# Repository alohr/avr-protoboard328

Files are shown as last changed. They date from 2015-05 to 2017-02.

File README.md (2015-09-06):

avr-protoboard328
=================

A prototyping board for the AVR atmega328p. 

## Images

<p align="center">
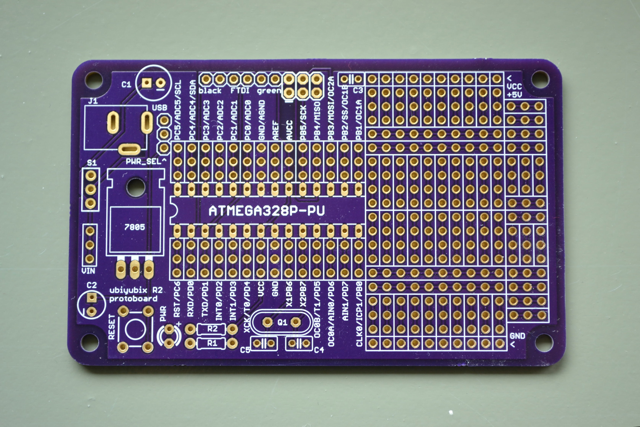
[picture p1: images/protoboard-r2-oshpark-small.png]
r2 from oshpark
  
</p>

<p align="center">
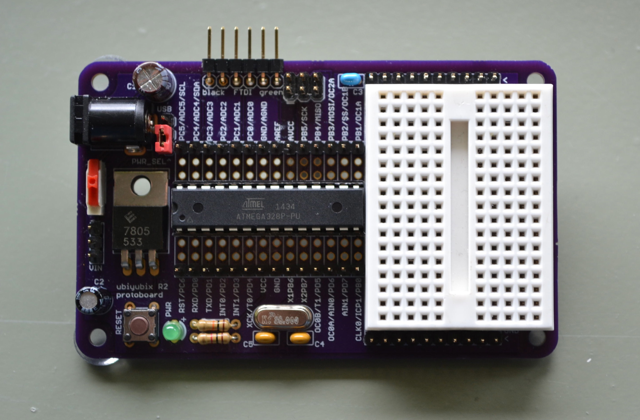
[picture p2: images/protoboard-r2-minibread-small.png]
r2 from oshpark w/ mini breadboard
  
</p>

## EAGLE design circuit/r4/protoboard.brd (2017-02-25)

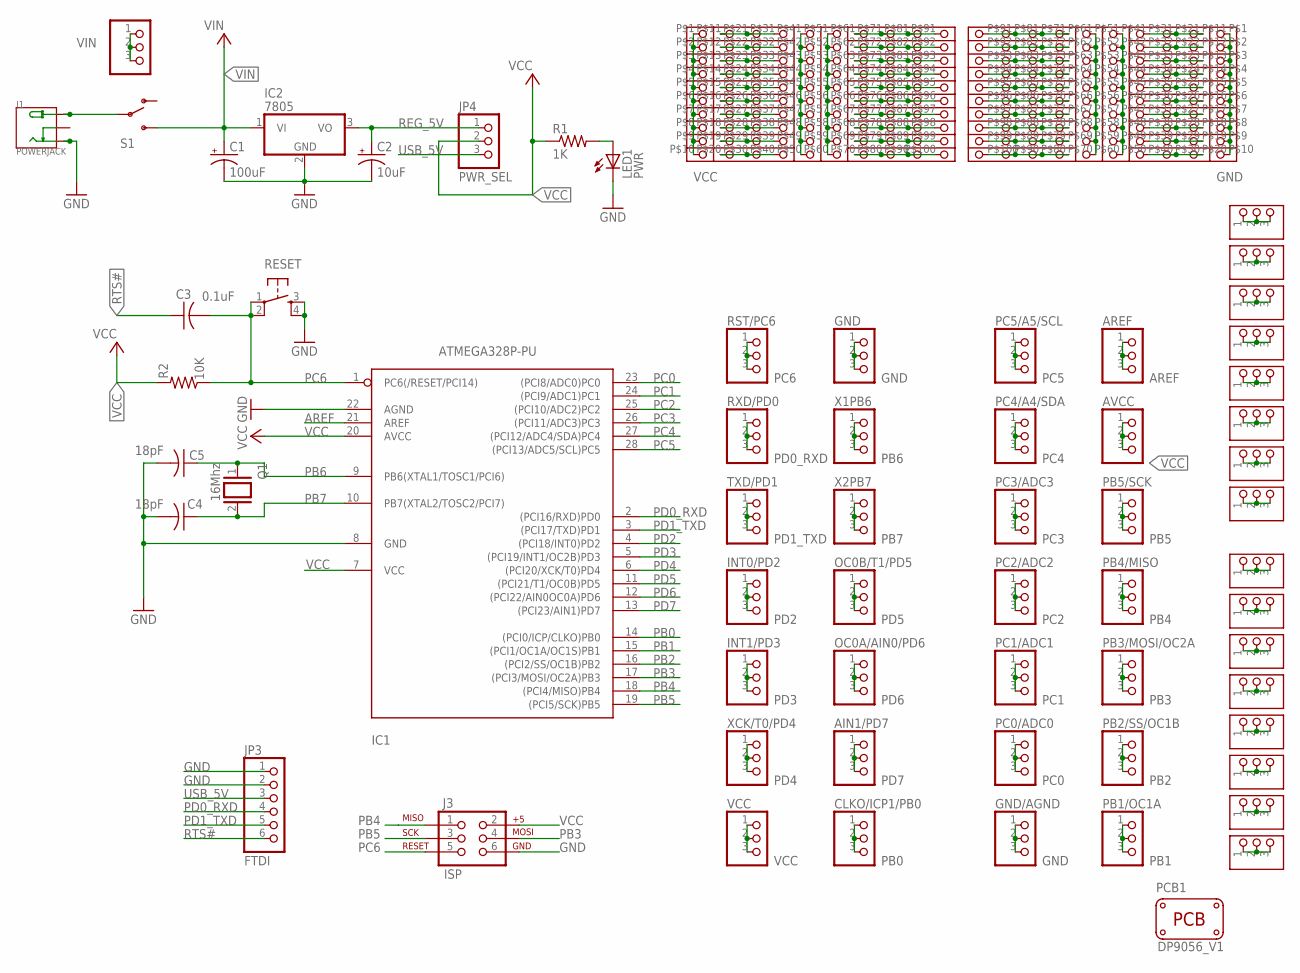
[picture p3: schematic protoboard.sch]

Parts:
AIN1/PD7: PINHD-1X3; 1X03
AREF: PINHD-1X3; 1X03
AVCC: PINHD-1X3; 1X03
C1: 100uF; CPOL-RADIAL-100UF-25V
C2: 10uF; CPOL-RADIAL-10UF-25V
C3: 0.1uF; C025-025X050
C4, C5: 18pF; C025-025X050
CLKO/ICP1/PB0: PINHD-1X3; 1X03
GND: PINHD-1X3; 1X03
GND/AGND: PINHD-1X3; 1X03
IC1: ATMEGA328P-PU; DIL28-3
IC2: 7805; TO220H
INT0/PD2, INT1/PD3: PINHD-1X3; 1X03
J1: POWERJACK; PW-3P-2.1
J3: ISP; 2X3
JP3: FTDI; 1X06
JP4: PWR_SEL; 1X03
LED1: PWR; LED3MM
OC0A/AIN0/PD6, OC0B/T1/PD5: PINHD-1X3; 1X03
PB1/OC1A, PB2/SS/OC1B, PB3/MOSI/OC2A, PB4/MISO, PB5/SCK: PINHD-1X3; 1X03
PC0/ADC0, PC1/ADC1, PC2/ADC2, PC3/ADC3, PC4/A4/SDA, PC5/A5/SCL: PINHD-1X3; 1X03
PCB1: PCB_DP_RECTANGLE-56X90; DP9056_V1
Q1: 16Mhz; QS
R1: 1K; 0207/7
R2: 10K; 0207/7
RESET: TAC_SWITCHPTH; TACTILE-PTH
RST/PC6: PINHD-1X3; 1X03
RXD/PD0: PINHD-1X3; 1X03
S1: SWITCH-SPDTPTH; SWITCH-SPDT
TXD/PD1: PINHD-1X3; 1X03
U$1, U$3: PROTOFIELD-10X10
U$4, U$5, U$6, U$7, U$8, U$9, U$10, U$11, U$12, U$13, U$14, U$15, U$16, U$17, U$18, U$19: PROTOFIELD-3
VCC: PINHD-1X3; 1X03
VIN: +9V; 1X03
X1PB6, X2PB7: PINHD-1X3; 1X03
XCK/T0/PD4: PINHD-1X3; 1X03

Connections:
AREF: AREF.1, AREF.2, AREF.3, IC1.21 (AREF)
GND: C1.2 (-), C2.2 (-), C4.2, C5.2, GND.1, GND.2, GND.3, GND/AGND.1, GND/AGND.2, GND/AGND.3, IC1.8 (GND), IC1.22 (AGND), IC2.2 (GND), J1.-1 (-), J3.6, JP3.1, JP3.2, LED1.K (C), RESET.3, RESET.4, U$3.P$1 (1), U$3.P$2 (5), U$3.P$3, U$3.P$4, U$3.P$5, U$3.P$6, U$3.P$7, U$3.P$8, U$3.P$9, U$3.P$10
unnamed: J1.+, S1.2
unnamed: LED1.A, R1.2
unnamed: U$4.1, U$4.2, U$4.3
unnamed: U$5.1, U$5.2, U$5.3
unnamed: U$6.1, U$6.2, U$6.3
unnamed: U$7.1, U$7.2, U$7.3
unnamed: U$8.1, U$8.2, U$8.3
unnamed: U$9.1, U$9.2, U$9.3
unnamed: U$10.1, U$10.2, U$10.3
unnamed: U$11.1, U$11.2, U$11.3
unnamed: U$12.1, U$12.2, U$12.3
unnamed: U$13.1, U$13.2, U$13.3
unnamed: U$14.1, U$14.2, U$14.3
unnamed: U$15.1, U$15.2, U$15.3
unnamed: U$16.1, U$16.2, U$16.3
unnamed: U$17.1, U$17.2, U$17.3
unnamed: U$18.1, U$18.2, U$18.3
unnamed: U$19.1, U$19.2, U$19.3
unnamed: U$1.P$41, U$1.P$42, U$1.P$43, U$1.P$44, U$1.P$45, U$1.P$46, U$1.P$47, U$1.P$48, U$1.P$49, U$1.P$50
unnamed: U$1.P$51, U$1.P$52, U$1.P$53, U$1.P$54, U$1.P$55, U$1.P$56, U$1.P$57, U$1.P$58, U$1.P$59, U$1.P$60
unnamed: U$1.P$61, U$1.P$71, U$1.P$81, U$1.P$91
unnamed: U$1.P$62, U$1.P$72, U$1.P$82, U$1.P$92
unnamed: U$1.P$63, U$1.P$73, U$1.P$83, U$1.P$93
unnamed: U$1.P$64, U$1.P$74, U$1.P$84, U$1.P$94
unnamed: U$1.P$65, U$1.P$75, U$1.P$85, U$1.P$95
unnamed: U$1.P$66, U$1.P$76, U$1.P$86, U$1.P$96
unnamed: U$1.P$67, U$1.P$77, U$1.P$87, U$1.P$97
unnamed: U$1.P$68, U$1.P$78, U$1.P$88, U$1.P$98
unnamed: U$1.P$69, U$1.P$79, U$1.P$89, U$1.P$99
unnamed: U$1.P$70, U$1.P$80, U$1.P$90, U$1.P$100
unnamed: U$1.P$11 (2), U$1.P$21 (3), U$1.P$31 (4)
unnamed: U$1.P$12 (6), U$1.P$22 (7), U$1.P$32 (8)
unnamed: U$1.P$13, U$1.P$23, U$1.P$33
unnamed: U$1.P$14, U$1.P$24, U$1.P$34
unnamed: U$1.P$15, U$1.P$25, U$1.P$35
unnamed: U$1.P$16, U$1.P$26, U$1.P$36
unnamed: U$1.P$17, U$1.P$27, U$1.P$37
unnamed: U$1.P$18, U$1.P$28, U$1.P$38
unnamed: U$1.P$19, U$1.P$29, U$1.P$39
unnamed: U$1.P$20, U$1.P$30, U$1.P$40
unnamed: U$3.P$61, U$3.P$71, U$3.P$81, U$3.P$91
unnamed: U$3.P$62, U$3.P$72, U$3.P$82, U$3.P$92
unnamed: U$3.P$63, U$3.P$73, U$3.P$83, U$3.P$93
unnamed: U$3.P$64, U$3.P$74, U$3.P$84, U$3.P$94
unnamed: U$3.P$65, U$3.P$75, U$3.P$85, U$3.P$95
unnamed: U$3.P$66, U$3.P$76, U$3.P$86, U$3.P$96
unnamed: U$3.P$67, U$3.P$77, U$3.P$87, U$3.P$97
unnamed: U$3.P$68, U$3.P$78, U$3.P$88, U$3.P$98
unnamed: U$3.P$69, U$3.P$79, U$3.P$89, U$3.P$99
unnamed: U$3.P$70, U$3.P$80, U$3.P$90, U$3.P$100
unnamed: U$3.P$51, U$3.P$52, U$3.P$53, U$3.P$54, U$3.P$55, U$3.P$56, U$3.P$57, U$3.P$58, U$3.P$59, U$3.P$60
unnamed: U$3.P$41, U$3.P$42, U$3.P$43, U$3.P$44, U$3.P$45, U$3.P$46, U$3.P$47, U$3.P$48, U$3.P$49, U$3.P$50
unnamed: U$3.P$11 (2), U$3.P$21 (3), U$3.P$31 (4)
unnamed: U$3.P$12 (6), U$3.P$22 (7), U$3.P$32 (8)
unnamed: U$3.P$13, U$3.P$23, U$3.P$33
unnamed: U$3.P$14, U$3.P$24, U$3.P$34
unnamed: U$3.P$15, U$3.P$25, U$3.P$35
unnamed: U$3.P$16, U$3.P$26, U$3.P$36
unnamed: U$3.P$17, U$3.P$27, U$3.P$37
unnamed: U$3.P$18, U$3.P$28, U$3.P$38
unnamed: U$3.P$19, U$3.P$29, U$3.P$39
unnamed: U$3.P$20, U$3.P$30, U$3.P$40
PB0: CLKO/ICP1/PB0.1, CLKO/ICP1/PB0.2, CLKO/ICP1/PB0.3, IC1.14 ((PCI0/ICP/CLKO)PB0)
PB1: IC1.15 ((PCI1/OC1A/OC1S)PB1), PB1/OC1A.1, PB1/OC1A.2, PB1/OC1A.3
PB2: IC1.16 ((PCI2/SS/OC1B)PB2), PB2/SS/OC1B.1, PB2/SS/OC1B.2, PB2/SS/OC1B.3
PB3: IC1.17 ((PCI3/MOSI/OC2A)PB3), J3.4, PB3/MOSI/OC2A.1, PB3/MOSI/OC2A.2, PB3/MOSI/OC2A.3
PB4: IC1.18 ((PCI4/MISO)PB4), J3.1, PB4/MISO.1, PB4/MISO.2, PB4/MISO.3
PB5: IC1.19 ((PCI5/SCK)PB5), J3.3, PB5/SCK.1, PB5/SCK.2, PB5/SCK.3
PB6: C5.1, IC1.9 (PB6(XTAL1/TOSC1/PCI6)), Q1.1, X1PB6.1, X1PB6.2, X1PB6.3
PB7: C4.1, IC1.10 (PB7(XTAL2/TOSC2/PCI7)), Q1.2, X2PB7.1, X2PB7.2, X2PB7.3
PC0: IC1.23 ((PCI8/ADC0)PC0), PC0/ADC0.1, PC0/ADC0.2, PC0/ADC0.3
PC1: IC1.24 ((PCI9/ADC1)PC1), PC1/ADC1.1, PC1/ADC1.2, PC1/ADC1.3
PC2: IC1.25 ((PCI10/ADC2)PC2), PC2/ADC2.1, PC2/ADC2.2, PC2/ADC2.3
PC3: IC1.26 ((PCI11/ADC3)PC3), PC3/ADC3.1, PC3/ADC3.2, PC3/ADC3.3
PC4: IC1.27 ((PCI12/ADC4/SDA)PC4), PC4/A4/SDA.1, PC4/A4/SDA.2, PC4/A4/SDA.3
PC5: IC1.28 ((PCI13/ADC5/SCL)PC5), PC5/A5/SCL.1, PC5/A5/SCL.2, PC5/A5/SCL.3
PC6: C3.2, IC1.1 (PC6(/RESET/PCI14)), J3.5, R2.1, RESET.1, RESET.2, RST/PC6.1, RST/PC6.2, RST/PC6.3
PD0_RXD: IC1.2 ((PCI16/RXD)PD0), JP3.4, RXD/PD0.1, RXD/PD0.2, RXD/PD0.3
PD1_TXD: IC1.3 ((PCI17/TXD)PD1), JP3.5, TXD/PD1.1, TXD/PD1.2, TXD/PD1.3
PD2: IC1.4 ((PCI18/INT0)PD2), INT0/PD2.1, INT0/PD2.2, INT0/PD2.3
PD3: IC1.5 ((PCI19/INT1/OC2B)PD3), INT1/PD3.1, INT1/PD3.2, INT1/PD3.3
PD4: IC1.6 ((PCI20/XCK/T0)PD4), XCK/T0/PD4.1, XCK/T0/PD4.2, XCK/T0/PD4.3
PD5: IC1.11 ((PCI21/T1/OC0B)PD5), OC0B/T1/PD5.1, OC0B/T1/PD5.2, OC0B/T1/PD5.3
PD6: IC1.12 ((PCI22/AIN0OC0A)PD6), OC0A/AIN0/PD6.1, OC0A/AIN0/PD6.2, OC0A/AIN0/PD6.3
PD7: AIN1/PD7.1, AIN1/PD7.2, AIN1/PD7.3, IC1.13 ((PCI23/AIN1)PD7)
REG_5V: C2.1 (+), IC2.3 (VO), JP4.1
RTS#: C3.1, JP3.6
USB_5V: JP3.3, JP4.3
VCC: AVCC.1, AVCC.2, AVCC.3, IC1.7 (VCC), IC1.20 (AVCC), J3.2, JP4.2, R1.1, R2.2, U$1.P$1 (1), U$1.P$2 (5), U$1.P$3, U$1.P$4, U$1.P$5, U$1.P$6, U$1.P$7, U$1.P$8, U$1.P$9, U$1.P$10, VCC.1, VCC.2, VCC.3
VIN: C1.1 (+), IC2.1 (VI), S1.3 (S), VIN.1, VIN.2, VIN.3

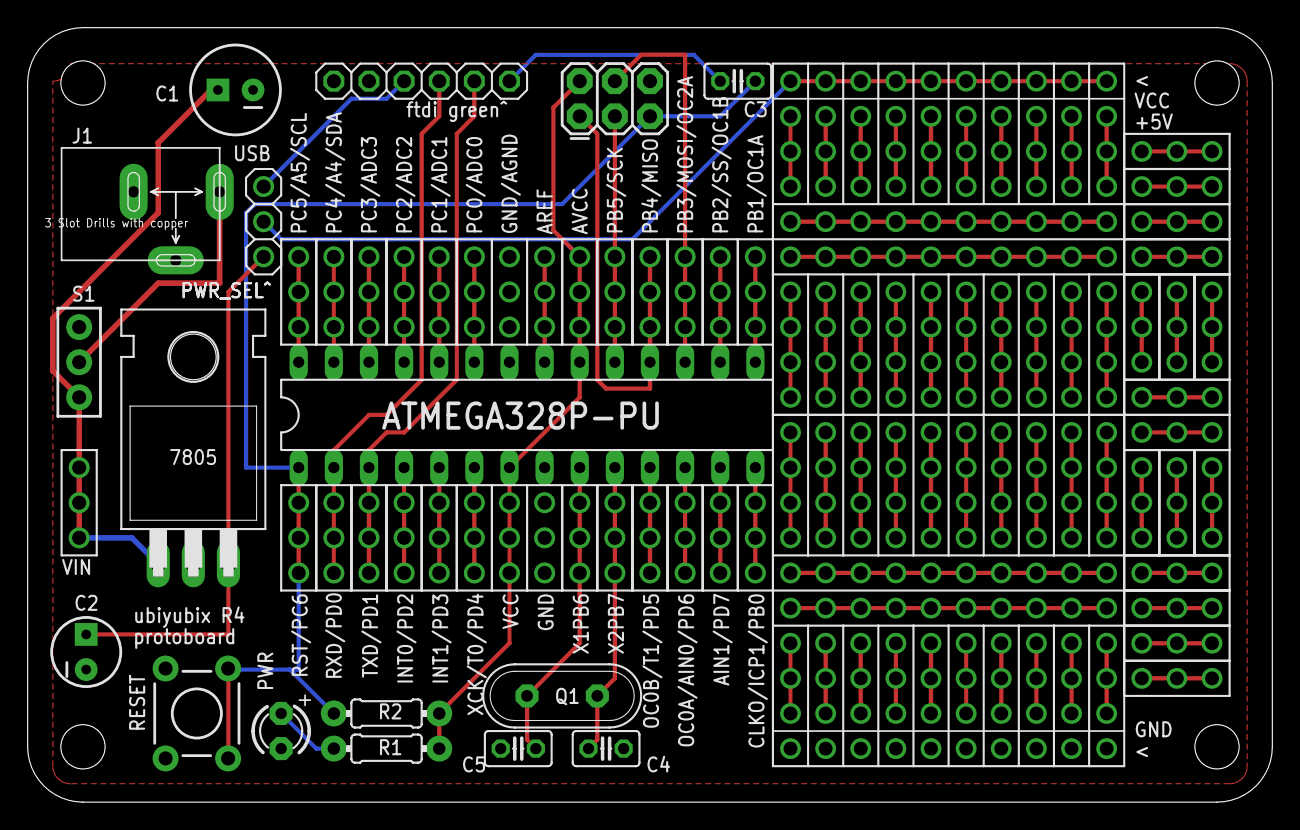
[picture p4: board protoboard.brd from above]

Board: 2 copper layers, 90.0 x 56.0 mm, 65 parts (0 on the bottom side), 92 nets.

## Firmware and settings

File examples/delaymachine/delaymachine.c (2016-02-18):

#include <avr/io.h>
#include <avr/interrupt.h>
#include <util/delay.h>

#include "timer0.h"

//                           +-\/-+
//               reset PC6  1|    |28  PC5 display cathode 3
// display anode seg A PD0  2|    |27  PC4 display cathode 2
// display anode seg B PD1  3|    |26  PC3 display cathode 1
// display anode seg C PD2  4|    |25  PC2 display cathode 0
// display anode seg D PD3  5|    |24  PC1
// display anode seg E PD4  6|    |23  PC0 ADC0 potentiometer
//                     VCC  7|    |22  GND
//                     GND  8|    |21  AREF
//               XTAL1 PB6  9|    |20  AVCC
//               XTAL2 PB7 10|    |19  PB5
// display anode seg F PD5 11|    |18  PB4
// display anode seg G PD6 12|    |17  PB3
//       push button 2 PD7 13|    |16  PB2 led cathode
//       push button 1 PB0 14|    |15  PB1 OC1A pwm output
//                           +----+

#if F_CPU == 1000000
  #define TIMER2_PRESCALE 8
#elif F_CPU == 8000000 || F_CPU == 16000000
  #define TIMER2_PRESCALE 64
#else
  #error F_CPU not recognized
#endif

enum {
    TIMER2_RESET_TO_400_MICROS = 256 - (F_CPU / TIMER2_PRESCALE / 2500),

    PIN_LED = PB2,
    PIN_BUTTON1 = PB0,
    PIN_BUTTON2 = PD7,

    PIN_CATHODE_DIGIT_0 = PC2,
    PIN_CATHODE_DIGIT_1 = PC3,
    PIN_CATHODE_DIGIT_2 = PC4,
    PIN_CATHODE_DIGIT_3 = PC5,
    PIN_CATHODES_MASK = (_BV(PIN_CATHODE_DIGIT_0) | _BV(PIN_CATHODE_DIGIT_1) |
                         _BV(PIN_CATHODE_DIGIT_2) | _BV(PIN_CATHODE_DIGIT_3)),

    PIN_ANODE_SEG_A = PD0,
    PIN_ANODE_SEG_B = PD1,
    PIN_ANODE_SEG_C = PD2,
    PIN_ANODE_SEG_D = PD3,
    PIN_ANODE_SEG_E = PD4,
    PIN_ANODE_SEG_F = PD5,
    PIN_ANODE_SEG_G = PD6,
    PIN_ANODES_MASK = (_BV(PIN_ANODE_SEG_A) | _BV(PIN_ANODE_SEG_B) | _BV(PIN_ANODE_SEG_C) |
                       _BV(PIN_ANODE_SEG_D) | _BV(PIN_ANODE_SEG_E) | _BV(PIN_ANODE_SEG_F) |
                       _BV(PIN_ANODE_SEG_G))
};

static int segment[] = {
    0b00111111, // 0
    0b00000110, // 1
    0b01011011, // 2
    0b01001111, // 3
    0b01100110, // 4
    0b01101101, // 5
    0b01111101, // 6
    0b00000111, // 7
    0b01111111, // 8
    0b01101111, // 9
};

typedef struct {
    uint8_t digits[4];
    uint8_t digit;
    uint8_t segment;
    int value;
    int on;
} display_t;

typedef struct {
    int raw, prevraw;
    int v;
    long t;
} analogvalue_t;

static volatile display_t display;

static void display_update(volatile display_t *d)
{
    if (d->on) {
        // digit
        uint8_t port_c = PORTC;
        port_c |= PIN_CATHODES_MASK;

        switch (d->digit) {
        case 0:
            port_c &= ~_BV(PIN_CATHODE_DIGIT_0);
            break;
        case 1:
            if (d->digits[1] != 0)
                port_c &= ~_BV(PIN_CATHODE_DIGIT_1);
            break;
        case 2:
            if (d->digits[2] != 0)
                port_c &= ~_BV(PIN_CATHODE_DIGIT_2);
            break;
        case 3:
            if (d->digits[3] != 0)
                port_c &= ~_BV(PIN_CATHODE_DIGIT_3);
            break;
        }

        PORTC = port_c;

        // segment
        int value = d->digits[d->digit];
        uint8_t port_d = (PORTD & _BV(PD7));
        PORTD = (segment[value] & _BV(d->segment)) | port_d;

        if (++d->segment == 7) {
            d->segment = 0;
            if (++d->digit == 4)
                d->digit = 0;
        }
    }
}

static void display_on(volatile display_t *d, int on)
{
    cli();
    d->on = on;
    sei();
}

static void display_off(volatile display_t *d)
{
    display_on(d, 0);
}

void display_toggle(volatile display_t *d)
{
    cli();
    d->on = !d->on;
    if (!d->on)
        display_off(d);
    sei();
}

static void display_set(volatile display_t *d, int value)
{
    d->digits[0] = value % 10;
    d->digits[1] = (value / 10) % 10;
    d->digits[2] = (value / 100) % 10;
    d->digits[3] = (value / 1000) % 10;
    d->value = value;
}

ISR(TIMER2_OVF_vect)
{
    // timer interrupt overflows every 400 microseconds
    TCNT2 = TIMER2_RESET_TO_400_MICROS;
    display_update(&display);
}

void setup_timer2(void)
{
#if F_CPU == 8000000
    // prescale /32
    TCCR2A = 0;
    TCCR2B = _BV(CS21) | _BV(CS20);
#elif F_CPU == 16000000
    // prescale /64
    TCCR2A = 0;
    TCCR2B = _BV(CS22);
#else
#error F_CPU not recognized
#endif

    // overflow interrupt enable
    TIMSK2 |= _BV(TOIE2);
    TCNT2 = TIMER2_RESET_TO_400_MICROS;

    sei();
}

void setup(void)
{
    // turn rx/tx on PD0 and PD1 off
    UCSR0B = 0;

    // display anodes PD0 .. PD6
    DDRD = PIN_ANODES_MASK;

    // display cathodes
    DDRC = PIN_CATHODES_MASK;
    PORTC |= PIN_CATHODES_MASK;

    // Set ADC prescaler /128, 16 Mhz / 128 = 125 KHz which is inside
    // the desired 50-200 KHz range
    ADCSRA = _BV(ADEN) | _BV(ADPS2) | _BV(ADPS1) | _BV(ADPS0);

    // LED pin
    DDRB |= _BV(PIN_LED);
    PORTB |= _BV(PIN_LED);
}

void analog_init(analogvalue_t *value)
{
    value->raw = 0;
    value->prevraw = 0;
    value->v = 0;
    value->t = millis();
}

int analog_read(int chan, analogvalue_t *value)
{
    uint8_t low, high;

    // AVCC with external capacitor at AREF pin, select channel
    ADMUX = (_BV(REFS0) | (chan & 0x0f));

    // start single conversion
    ADCSRA |= _BV(ADSC);

    // wait for conversion to complete
    loop_until_bit_is_clear(ADCSRA, ADSC);

    low  = ADCL;
    high = ADCH;

    value->raw = (high << 8) | low;
    value->t = millis();

    return value->raw;
}

int potentiometer_read(analogvalue_t *value)
{
    analogvalue_t newvalue;
    enum { CHANNEL = 0, N_READINGS = 3 };

    int raw = 0;
    for (int i = 0; i < N_READINGS; i++) {
        analog_read(CHANNEL, &newvalue);
        raw += newvalue.raw;
    }

    newvalue.raw = raw / N_READINGS;
    if (newvalue.raw > 1020)
        newvalue.raw = 1020;

    if ((newvalue.raw > value->prevraw && newvalue.raw - value->prevraw > 3) ||
        (newvalue.raw < value->prevraw && value->prevraw - newvalue.raw > 3)) {

        if (newvalue.t - value->t > 50) {
            value->prevraw = value->raw;
            value->raw = newvalue.raw;
            value->v = newvalue.raw / 4;
            value->t = newvalue.t;
        }
    }

    return value->v;
}

void settle_on_low(volatile uint8_t *port, uint8_t mask)
{
    long t = 0, t0 = 0;
    enum { SETTLE_ON_LOW_TIMEOUT_MS = 20 };

    loop_until_bit_is_clear(*port, mask);
    t0 = millis();

    // now wait for pin to stay low for at least x milliseconds
    while ((t = millis()) - t0 < SETTLE_ON_LOW_TIMEOUT_MS) {
	if (bit_is_set(*port, mask))
	    t0 = millis();
    }
}

/*
void setup_int0(void)
{
    // set INT0 to trigger on falling edge
    EICRA |= _BV(ISC01);
    EICRA &= ~_BV(ISC00);
}

void enable_int0()
{
    EIMSK |= _BV(INT0);
}

void disable_int0()
{
    EIMSK &= ~_BV(INT0);
}
*/

/* volatile long t0 = 0; */

/* ISR(INT0_vect) */
/* { */
/*     disable_int0(); */
/*     t0 = micros(); */
/* } */

int main(void)
{
    analogvalue_t delay;

    setup();
    setup_timer0();

    // setup_int0();

    // display_off(&display);
    setup_timer2();

    analog_init(&delay);
    potentiometer_read(&delay);

    display_set(&display, delay.v);
    display_on(&display, 1);

    /* if ((PIND & _BV(PIN_SW1)) == 0) */
    /*     pin = PIN_LED_RED; */

    for (;;) {
        if ((PIND & _BV(PIN_BUTTON2)) == 0) {
            PORTB &= _BV(PIN_LED);
        } else {
            PORTB |= _BV(PIN_LED);
        }



/*
        if ((PIND & _BV(PIN_SW1)) == 0) {
            long tmax = 1000L * delay.v;
            while (micros() - t0 < tmax)
                ;
            PORTD |= _BV(pin);
        } else {
            PORTD &= ~_BV(pin);
            enable_int0();
        }

        if ((PIND & _BV(PIN_SW2)) == 0) {
            settle_on_low(&PIND, PIN_SW2);
            loop_until_bit_is_set(PIND, PIN_SW2);
            display_toggle(&display);
        }
*/

        potentiometer_read(&delay);
        if (delay.v != display.value) {
            display_set(&display, delay.v);
        }
    }

    return 0;
}

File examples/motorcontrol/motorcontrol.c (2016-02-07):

#include <avr/io.h>
#include <avr/interrupt.h>
#include <util/delay.h>

//#define ONE_DIRECTION 
#define TWO_DIRECTIONS

#if !defined(ONE_DIRECTION) && !defined(TWO_DIRECTIONS)
#error Must define either ONE_DIRECTION or TWO_DIRECTIONS
#elif defined(ONE_DIRECTION) && defined(TWO_DIRECTIONS)
#error Must not define ONE_DIRECTION and TWO_DIRECTIONS
#endif

#define TIMER1_CLKFUDGE 3
#define TIMER1_GETVALUE(x) ((x) >> 1)

#define TIMER2_PRESCALE_DIVIDER 256
#define PWM_MIN 0x40
#define PWM_MAX 0xff

#define PULSEWIDTH_MARGIN 10
#define PULSEWIDTH_MIN 1000
#define PULSEWIDTH_MID 1500
#define PULSEWIDTH_MAX 2000

#define BACKWARD 0
#define FORWARD 1

// --------------------------
// TIMER1 - input capture
// --------------------------

volatile uint16_t pulsewidth = 0; // set by TIMER1_CAPT_vect interrupt routine

ISR(TIMER1_CAPT_vect)
{
    uint16_t icr1 = ICR1;
    TCNT1 = 0;

    if (bit_is_set(TCCR1B, ICES1)) {
        // was rising edge -> set to detect falling edge
        TCCR1B &= ~_BV(ICES1);
    } else {
        pulsewidth = icr1 + TIMER1_CLKFUDGE;
        // was falling -> now set to detect rising edge
        TCCR1B |= _BV(ICES1);
    }
}

void setup_timer1(void)
{
    TCCR1A = 0;

    TCCR1B |= _BV(ICES1); // trigger input capture on rising edge
    TCCR1B |= _BV(CS11);  // set prescaler /8

    TIMSK1 = _BV(ICIE1);  // input capture interrupt enable
}

// --------------------------
// TIMER2 - motor pwm control
// --------------------------

void setup_timer2(void)
{
    TCCR2A = 0;
    TCCR2B = 0;

#if F_CPU == 16000000
#if TIMER2_PRESCALE_DIVIDER == 1
    // no prescale 
    TCCR2B &= ~_BV(CS22);
    TCCR2B &= ~_BV(CS21);
    TCCR2B |= _BV(CS20);
#elif TIMER2_PRESCALE_DIVIDER == 8
    // prescale /8
    TCCR2B &= ~_BV(CS22);
    TCCR2B |= _BV(CS21);
    TCCR2B &= ~_BV(CS20);
#elif TIMER2_PRESCALE_DIVIDER == 32
    // prescale /32
    TCCR2B &= ~_BV(CS22);
    TCCR2B |= _BV(CS21);
    TCCR2B |= _BV(CS20);
#elif TIMER2_PRESCALE_DIVIDER == 64
    // prescale /64
    TCCR2B |= _BV(CS22);
    TCCR2B &= ~_BV(CS21);
    TCCR2B &= ~_BV(CS20);
#elif TIMER2_PRESCALE_DIVIDER == 256
    // prescale /256
    TCCR2B |= _BV(CS22);
    TCCR2B |= _BV(CS21);
    TCCR2B &= ~_BV(CS20);
#elif TIMER2_PRESCALE_DIVIDER == 1024
    // prescale /1024
    TCCR2B |= _BV(CS22);
    TCCR2B |= _BV(CS21);
    TCCR2B |= _BV(CS20);
#else
#error TIMER2_PRESCALE_DIVIDER not set correctly
#endif
#else
#error F_CPU not recognized
#endif

    // fast pwm mode 3
    TCCR2A |= _BV(WGM21) | _BV(WGM20);
    TCCR2B &= ~_BV(WGM22);
}

void timer2_set_oc2a(uint8_t ocr2a)
{
    if (ocr2a) {
        // clear OC2A on compare match (non-inverting mode)
        TCCR2A |= _BV(COM2A1);
        TCCR2A &= ~_BV(COM2A0);
        OCR2A = ocr2a;
    } else {
        // OC2A disconnected
        TCCR2A &= ~(_BV(COM2A1) | _BV(COM2A0));
    }
}

void setup(void)
{
    setup_timer1();
    setup_timer2();

    DDRB &= ~_BV(PB0); // ICP1 input pin = PB0
    
    // LD293 control pins
    DDRB |= _BV(PB1) | _BV(PB2) | _BV(PB3);
}

long map(int x, long in_min, long in_max, long out_min, long out_max)
{
    return (x - in_min) * (out_max - out_min) / (in_max - in_min) + out_min;
}

void set_motor_pins(int direction, uint8_t pwm)
{
    if (pwm != 0 && direction == BACKWARD) {
        PORTB &= ~_BV(PB2);
        PORTB |= _BV(PB1);
    } else if (pwm != 0 && direction == FORWARD) {
        PORTB &= ~_BV(PB1);
        PORTB |= _BV(PB2);
    } else {
        PORTB &= ~_BV(PB1);
        PORTB &= ~_BV(PB2);
    }
    timer2_set_oc2a(pwm);
}

void one_direction(uint16_t reading)
{
    if (reading > PULSEWIDTH_MAX - PULSEWIDTH_MARGIN) {
        // full speed
        set_motor_pins(FORWARD, 0xff);
    } else if (reading < (PULSEWIDTH_MIN + PULSEWIDTH_MARGIN)) {
        // off
        set_motor_pins(FORWARD, 0);
    } else {
        set_motor_pins(FORWARD, map(reading, 1000, 2000, PWM_MIN, PWM_MAX));
    }
}

void two_directions(uint16_t reading)
{
    if (reading < PULSEWIDTH_MID - PULSEWIDTH_MARGIN) {
        // backward
        if (reading < PULSEWIDTH_MIN + PULSEWIDTH_MARGIN) {
            // full speed
            set_motor_pins(BACKWARD, 0xff);
        } else {
            uint8_t pwm = PWM_MAX - map(reading, 1000, 1500, PWM_MIN, PWM_MAX);
            set_motor_pins(BACKWARD, pwm);
        }
    } else if (reading > PULSEWIDTH_MID + PULSEWIDTH_MARGIN) {
        // forward
        if (reading > PULSEWIDTH_MAX - PULSEWIDTH_MARGIN) {
            // full speed
            set_motor_pins(FORWARD, 0xff);
        } else {
            set_motor_pins(FORWARD, map(reading, PULSEWIDTH_MID, PULSEWIDTH_MAX, 0x40, 0xff));
        }
    } else {
        set_motor_pins(FORWARD, 0);
    }
}

int main(void)
{
    setup();
    sei();

    PORTB |= _BV(PB2);

    for (;;) {
        uint16_t reading = TIMER1_GETVALUE(pulsewidth);

#if defined(ONE_DIRECTION)
        one_direction(reading);
#elif defined(TWO_DIRECTIONS)
        two_directions(reading);
#endif
        _delay_ms(10);

    }

    return 0;
}

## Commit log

2015-09-06 removed old files
    [protoboard.brd, protoboard.sch]
2015-09-06 added r3 eagle and gerber files
    [protoboard.brd, protoboard.sch]
2016-02-14 added pin usage
2016-02-17 reverse direction of potentiometer
    [bubbledisplay.c]
2016-02-17 use timer2 for display
2017-02-25 added r4
    [protoboard.brd, protoboard.sch]

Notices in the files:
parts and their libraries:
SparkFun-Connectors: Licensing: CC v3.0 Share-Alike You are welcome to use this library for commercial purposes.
